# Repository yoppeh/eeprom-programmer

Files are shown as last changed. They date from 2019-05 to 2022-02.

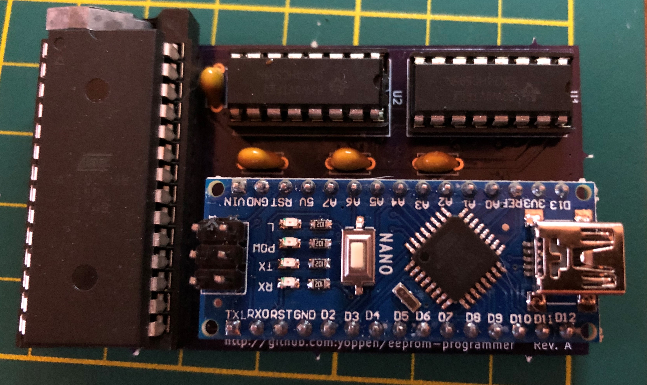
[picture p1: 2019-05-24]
populated-board.jpg

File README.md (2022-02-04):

# eeprom-programmer
An Arduino Nano sketch and schematic for an Atmel 28cx programmer. The schematic started out only targeting 8kx8 chips (rev. A) but has been updated to connect all address lines for the 28cx series (rev. B), so any of those eeproms should work up to the 32kx8 chips. The design is based on [this one](https://youtu.be/K88pgWhEb1M), from Ben Eater. 

The Arduino Nano sketch implements a serial interface to the programmer. It accepts one-letter commands:
- e - erase the eeprom
- f - fill eeprom with incrementing bytes
- h - help (this) text
- l - lock the eeprom against writes
- r - read and dump eeprom contents
- s - set the size of the eeprom
- u - unlock eeprom writes
- v - software version info
- x - xmodem transfer binary file to eeprom

Any standard terminal program can be used to talk to the programmer. I use the following:
- [serial](http://www.decisivetactics.com/products/serial/) for the Mac
- [teraterm](https://ttssh2.osdn.jp/index.html.en) for Windows
- [minicom](https://linux.die.net/man/1/minicom) for Linux

Be sure to set the size of your target eeprom with the s command before doing anything. It doesn't affect the chip in any way, but tells the programmer what size your chip is for the erase, fill and read commands and error checking in the xmodem transfer.

The programmer uses standard x-modem, as provided by any respectable terminal program—and certainly all of the
above listed terminal programs—to put binary files onto the eeprom. No other software is required. The programmer
will verify every 64 bytes as they are written (the size of an internal eeprom page).

Although the eeprom chips are supposed to come from the factory unlocked, I've heard stories of some chips being
purchased off ebay that arrive locked. Try doing an unlock on a chip if you have problems writing to it.

When doing an xmodem transfer to the chip, the program will wait indefinitely for you to start the xmodem transfer from your terminal software. You can abort the transfer at this point by pressing the ESC key. Otherwise, once you have started the transfer, it will continue until the process completes or an error is detected.

If you want to fill the eeprom with a specific byte, say the 6502 nop 0xea, just change

    fill[j] = i + j; 
on line 490 to

    fill[j] = 0xea;

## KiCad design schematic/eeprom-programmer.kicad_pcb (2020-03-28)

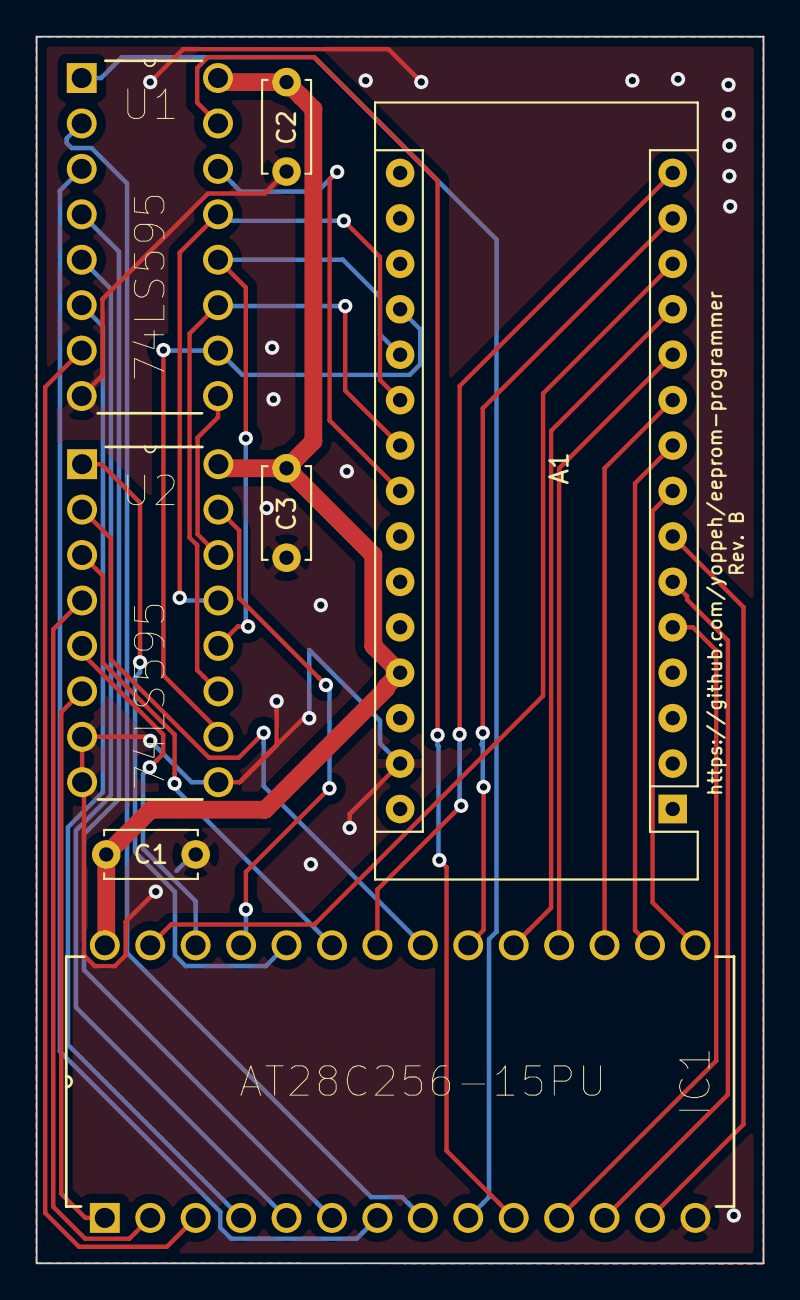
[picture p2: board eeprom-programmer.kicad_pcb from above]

Board: 2 copper layers, 40.6 x 68.6 mm, 7 parts (0 on the bottom side), 34 nets.

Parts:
A1: Arduino_Nano_v3.x; Arduino_Nano
C1, C2, C3: .1uf; C_Disc_D5.0mm_W2.5mm_P5.00mm
IC1: AT28C256-15PU; DIP254P1524X482-28
U1, U2: 74LS595; DIP254P762X508-16

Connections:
/addr00: IC1.10, U1.15
/addr01: IC1.9, U1.1
/addr02: IC1.8, U1.2
/addr03: IC1.7, U1.3
/addr04: IC1.6, U1.4
/addr05: IC1.5, U1.5
/addr06: IC1.4, U1.6
/addr07: IC1.3, U1.7
/addr08: IC1.25, U2.15
/addr09: IC1.24, U2.1
/addr10: IC1.21, U2.2
/addr11: IC1.23, U2.3
/addr12: IC1.2, U2.4
/addr13: IC1.26, U2.5
/addr14: IC1.1, U2.6
/data0: A1.5, IC1.11
/data1: A1.6, IC1.12
/data2: A1.7, IC1.13
/data3: A1.8, IC1.15
/data4: A1.9, IC1.16
/data5: A1.10, IC1.17
/data6: A1.11, IC1.18
/data7: A1.12, IC1.19
Arduino5V: A1.27, C1.2, C2.2, C3.2, IC1.28, U1.16, U2.16
GND: A1.29, C1.1, C2.1, C3.1, IC1.14, U1.8, U2.7, U2.8, U2.9
unnamed: U1.9, U2.14
eeNotChipEnable: A1.14, IC1.20
eeNotOutputEnable: A1.15, IC1.22
eeNotWriteEnable: A1.13, IC1.27
srNotOutputEnable: A1.21, U1.13, U2.13
srNotResetAll: A1.19, U1.10, U2.10
srReadClock: A1.20, U1.12, U2.12
srSerialClock: A1.22, U1.11, U2.11
srSerialData: A1.23, U1.14

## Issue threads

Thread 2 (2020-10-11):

using assignment operator instead of equality

btb, 2020-10-11:
you can't ever change the chip size because this always sets it back to 32768.

https://github.com/yoppeh/eeprom-programmer/blob/cc0bb88c09d81108247c1df810ca0ff00aa799d6/eeprom-programmer.ino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

btb, 2020-10-11:
well, I guess you can actually change it to 8192, in which case this line won't get reached, but if one is to modify this code to add more sizes, this will get in the way.

yoppeh, 2020-10-11:
Good eye, thank you!

Closed 2020-10-11.

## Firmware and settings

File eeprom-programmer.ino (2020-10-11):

/*******************************************************************************
 * eeprom-programmer.ino
 * 
 * Arduino Nano code for the at28c64b-15pu programmer. Note that this code is 
 * specific to the Nano (really, the ATmega328P). If you use this on another 
 * device, either make sure the port mappings are the same or you will need to
 * rewrite most of the code to use the correct mappings.
 *
 * I haven't looked at other EEPROMs, so I don't know how easy/difficult it 
 * would be to adapt this code to one. I'm not even sure if the pinouts for the
 * address lines or page sizes for the block write operations are the same
 * for different sizes of this same chip.
 *
 * The clock speed of the Nano (16MHz) is also assumed for getting the number
 * of nops to use for delays: 1 nop = 1 clock cycle = 1 / speed in MHz. So,
 * in the case of the Nano, 1 nop = 1 / 16000000 = 62.5ns.
 * 
 * Serial port settings:
 *  57600, 8n1, no flow control
 *
 * If you want to use other than 57600, change the SERIAL_BAUD constant below.
 *  
 * Terminal settings:
 *  turn off local echo
 *  Newline receive: LF
 *  Newline transmit: LF
 */


/* These are used in the x-modem protocol */
#define CHAR_SOH                0x01
#define CHAR_EOT                0x04
#define CHAR_ACK                0x06
#define CHAR_NAK                0x15
#define CHAR_ETB                0x17
#define CHAR_CAN                0x18
#define CHAR_ESC                0x1b
#define CHAR_C                  0x43

#define XMODEM_RETRIES          10
#define XMODEM_DELAY            2000
#define XMODEM_PACKET_MAX       128

/* Serial commands accepted by the programmer */
#define CMD_ERASE               'e'
#define CMD_FILL                'f'
#define CMD_HELP                'h'
#define CMD_LOCK                'l'
#define CMD_READ                'r'
#define CMD_SIZE                's'
#define CMD_UNLOCK              'u'
#define CMD_VERSION             'v'
#define CMD_XMODEM              'x'

/* Software version
 */
#define VERSION_MAJ             1
#define VERSION_MIN             2
#define VERSION_BLD             0

/* Change this to match whatever baud rate you want to use for the serial 
 * connection. 
 */
#define SERIAL_BAUD             57600

/* Set this to the size, in bytes of the EEPROM. In the case of the at28c64b,
 * it's 8k. 
 */
#define DEFAULT_EEPROM_SIZE     32768
#define PAGE_SIZE               64

/* Milliseconds to wait for a write to complete. */
#define WRITE_DELAY             25


/* Pin assignments
 *
 * These pin assigments correspond to these port mappings on the Atmega328P
 * (and Atmega168):
 *
 * x4HC595 shift registers
 *     PORTC, bit 4 = serial data pin (SER)
 *     PORTC, bit 3 = serial clock pin (SRCLK)
 *     PORTC, bit 2 = serial output enable (/OE)
 *     PORTC, bit 1 = serial read clock (RCLK)
 *     PORTC, bit 0 = reset all (/SRCLR)
 *
 * at28c64b eeprom
 *     PORTB, bit 4 = eeprom output enable (/OE)
 *     PORTB, bit 3 = eeprom chip enable (/CE)
 *     PORTB, bit 2 = eeprom write enable (/WE)
 *     PORTB, bit 1 = I/O7
 *     PORTB, bit 0 = I/O6
 *     PORTD, bit 7 = I/O5
 *     PORTD, bit 6 = I/O4  
 *     PORTD, bit 5 = I/O3
 *     PORTD, bit 4 = I/O2
 *     PORTD, bit 3 = I/O1
 *     PORTD, bit 2 = I/O0
 */
const int srSerialData = A4;
const int srSerialClock = A3;
const int srNotOutputEnable = A2;
const int srReadClock = A1;
const int srNotResetAll = A0;
const int eeNotWriteEnable = 10;
const int eeNotChipEnable = 11;
const int eeNotOutputEnable = 12;
const int eeD0 = 2;
const int eeD1 = 3;
const int eeD2 = 4;
const int eeD3 = 5;
const int eeD4 = 6;
const int eeD5 = 7;
const int eeD6 = 8;
const int eeD7 = 9;

unsigned int eeprom_size = DEFAULT_EEPROM_SIZE;


/* Clear the outputs of all shift registers to 0 by toggling the /srclr line.
 * /SRCLR needs to be low for 120ns, worst case. That's 3 nops, counting a
 * nop as 60ns.
 */
void sr_clear(void)
{
    PORTC = B00000100;
    __asm__ __volatile__ ("nop\n\t");
    __asm__ __volatile__ ("nop\n\t");
    __asm__ __volatile__ ("nop\n\t");
    PORTC = B00000101;
}


/* Setup the shift registers and shift in an address bit. Assumes that the bit
 * in question has already been shifted into bit 4: so, in the same position as
 * the "1" here: 00010000.
 */
void __attribute__((always_inline)) sr_shift_bit(byte bit)
{
    bit &= B00010000;
    // clear clock and data lines
    PORTC = B00000101 | bit;
    __asm__ __volatile__ ("nop\n\t");
    PORTC = B00001101 | bit;
    __asm__ __volatile__ ("nop\n\t");
}


/* Shifts out a given address on the 74HC595s.
 *
 * This is all about speed: no loops, no digitalRead()/Write(), always inline.
 * It's expected that the proper directions for the PORT bits used here are
 * already setup properly. Namely, PORTC bits 3 and 4 should be setup for
 * output.
 *
 * The observant programmer may notice we shift 16 bits onto the address lines.
 * This isn't a problem, even though we only have 13 address lines (on the
 * targetted 8k x 8 chip, chips with more memory, of course, will have more
 * address lines). The upper three bits simply aren't connected to anything and
 * the order in which the bits go out the shift registers guarantees that the
 * lower bits are always in the right place, no matter how many bits are 
 * shifted out. If this ends up being used with a larger EEPROM, then this
 * function at least won't have to be modified.
 */
void __attribute__((always_inline)) sr_address(word address)
{ 
    // disable output
    PORTC |= B00000100;

    // shift the address into the shift registers
    sr_shift_bit(address >> 11);
    sr_shift_bit(address >> 10);
    sr_shift_bit(address >> 9);
    sr_shift_bit(address >> 8);
    sr_shift_bit(address >> 7);
    sr_shift_bit(address >> 6);
    sr_shift_bit(address >> 5);
    sr_shift_bit(address >> 4);
    sr_shift_bit(address >> 3);
    sr_shift_bit(address >> 2);
    sr_shift_bit(address >> 1);
    sr_shift_bit(address);
    sr_shift_bit(address << 1);
    sr_shift_bit(address << 2);
    sr_shift_bit(address << 3);
    sr_shift_bit(address << 4);

    // make sure the clock and data lines are clear
    PORTC = B00000101;
    
    // put the address on the output pins by setting output enable low
    // and setting the read clock high
    PORTC = B00000011;
}


/* Puts a data value onto the data bus. The lower six bits of the data bus go
 * to the upper 6 bits of PORTD. PORTB's lower two bits hold the the upper two
 * bits of data. Again, this is about speed: The function is inline and uses
 * direct PORT writes. It's expected that all data pins are setup as OUTPUT
 * prior to this function being invoked.
 */
void __attribute__((always_inline)) write_data(byte data)
{
    PORTD = ((PORTD & B00000011) | (data << 2));
    PORTB = ((PORTB & B11111100) | (data >> 6));
}


/* Reads the data value in the EEPROM at the address currently on the address
 * pins. Assumes that the I/O lines are already setup as INPUTs and that the
 * /OE line is set properly.
 */
byte __attribute__((always_inline)) read_data(void)
{
    return ((PIND >> 2) | (PINB << 6));
}


/* Set all I/O (data) pins to output 
 */
void io_set_output(void)
{
    // all data pins are outputs
    DDRD |= B11111100;
    DDRB |= B00000011;
}


/* Set all I/O (data) pins to input 
 */
void io_set_input(void)
{
    // all data pins are inputs
    DDRD &= B00000011;
    DDRB &= B11111100;
}


/* Executes the appropriate write sequence to enable the software locking
 * mechanism of the chip. After this function executes, the chip will not
 * recognize writes unless unlock_chip() is called.
 */
int lock_chip(void)
{
    // Setup a known state. Enable chip.
    digitalWrite(eeNotChipEnable, LOW);
    digitalWrite(eeNotOutputEnable, HIGH);
    digitalWrite(eeNotWriteEnable, HIGH);

    // Set data lines to outputs
    io_set_output();

    // aah to address 1555h
    sr_address(0x1555);
    write_data(0xaa);
    digitalWrite(eeNotWriteEnable, LOW);
    digitalWrite(eeNotWriteEnable, HIGH);

    // 55h to address 0aaah
    sr_address(0x0aaa);
    write_data(0x55);
    digitalWrite(eeNotWriteEnable, LOW);
    digitalWrite(eeNotWriteEnable, HIGH);

    // a0h to address 1555h
    sr_address(0x1555);
    write_data(0xa0);
    digitalWrite(eeNotWriteEnable, LOW);
    digitalWrite(eeNotWriteEnable, HIGH);

    delay(WRITE_DELAY);

    return 1;
}


/* Disables the software write protect mechanism.
 */
int unlock_chip(void)
{
    // Setup a known state. Enable chip.
    digitalWrite(eeNotChipEnable, LOW);
    digitalWrite(eeNotOutputEnable, HIGH);
    digitalWrite(eeNotWriteEnable, HIGH);

    // Set data lines to outputs
    io_set_output();

    // aah to address 1555h
    sr_address(0x1555);
    write_data(0xaa);
    digitalWrite(eeNotWriteEnable, LOW);
    digitalWrite(eeNotWriteEnable, HIGH);

    // 55h to address 0aaah
    sr_address(0x0aaa);
    write_data(0x55);
    digitalWrite(eeNotWriteEnable, LOW);
    digitalWrite(eeNotWriteEnable, HIGH);

    // 80h to address 1555h
    sr_address(0x1555);
    write_data(0x80);
    digitalWrite(eeNotWriteEnable, LOW);
    digitalWrite(eeNotWriteEnable, HIGH);

    // aah to address 1555h
    sr_address(0x1555);
    write_data(0xaa);
    digitalWrite(eeNotWriteEnable, LOW);
    digitalWrite(eeNotWriteEnable, HIGH);

    // 55h to address 0aaah
    sr_address(0x0aaa);
    write_data(0x55);
    digitalWrite(eeNotWriteEnable, LOW);
    digitalWrite(eeNotWriteEnable, HIGH);

    // 20h to address 1555h
    sr_address(0x1555);
    write_data(0x20);
    digitalWrite(eeNotWriteEnable, LOW);
    digitalWrite(eeNotWriteEnable, HIGH);

    delay(WRITE_DELAY);

    return 1;
}


/* Writes a single input byte at a specified address.
 */
int write_byte(word address, byte data) 
{
    // set data lines as outputs
    io_set_output();

    // setup initial chip state
    digitalWrite(eeNotChipEnable, LOW);
    digitalWrite(eeNotOutputEnable, HIGH);
    digitalWrite(eeNotWriteEnable, HIGH);
    
    // set the address pins from the shift registers
    sr_address(address);

    // put the data on the EEPROM's i/o pins
    write_data(data);
    
    // setup the we-controlled write state
    digitalWrite(eeNotWriteEnable, LOW);
    
    // end the write state
    digitalWrite(eeNotWriteEnable, HIGH);

    delay(WRITE_DELAY);
    
    // byte was successfully written
    return 1;
}


/* Write a page of a given length (64 bytes max) at a given address.
 */
int write_page(word address, byte *data, byte len)
{
    // all data pins are outputs
    io_set_output();

    // setup initial state for control lines
    digitalWrite(eeNotChipEnable, LOW);
    digitalWrite(eeNotOutputEnable, HIGH);
    digitalWrite(eeNotWriteEnable, HIGH);

    while (len--) {
        // put address into shift registers
        sr_address(address++);
        // put data byte on EEPROM pins
        write_data(*data++);
        // bring write enable low
        digitalWrite(eeNotWriteEnable, LOW);
        // bring write enable high
        digitalWrite(eeNotWriteEnable, HIGH);
    }

    // turn off write state
    digitalWrite(eeNotWriteEnable, HIGH);
    digitalWrite(eeNotOutputEnable, LOW);

    // wait for updates to be committed to chip
    delay(WRITE_DELAY);
    
    return 1;
}


/* Write an xmodem packet 1 EEPROM page at a time. 
 */
void write_packet(word address, byte *data, word len)
{
    word i;
    
    for (i = 0; i < len; i += PAGE_SIZE, data += PAGE_SIZE) {
        write_page(address + i, data, PAGE_SIZE);
    }
}


/* Very that the received xmodem packet matches what was
 * written to the EEPROM.
 */
int verify_packet(word address, byte *data, word len)
{
    word i;

    for (i = 0; i < len; i++, address++, data++) {
        if (read_byte(address) != *data) {
            return 0;
        }
    }
    return 1;
}


/* Erase the EEPROM by writing all 1s to it. We do it this way, since the
 * hardware isn't there to do a hardware erase. That would require putting
 * a 12 volt line in the circuit, and... why bother...
 */
int erase_eeprom(void)
{
    byte fill[] = {
        0xff, 0xff, 0xff, 0xff, 0xff, 0xff, 0xff, 0xff, 
        0xff, 0xff, 0xff, 0xff, 0xff, 0xff, 0xff, 0xff,
        0xff, 0xff, 0xff, 0xff, 0xff, 0xff, 0xff, 0xff,
        0xff, 0xff, 0xff, 0xff, 0xff, 0xff, 0xff, 0xff,
        0xff, 0xff, 0xff, 0xff, 0xff, 0xff, 0xff, 0xff, 
        0xff, 0xff, 0xff, 0xff, 0xff, 0xff, 0xff, 0xff,
        0xff, 0xff, 0xff, 0xff, 0xff, 0xff, 0xff, 0xff, 
        0xff, 0xff, 0xff, 0xff, 0xff, 0xff, 0xff, 0xff
    };
    word i;
    for (i = 0; i < eeprom_size; i += PAGE_SIZE) {
        if (i % 1024 == 0) {
            Serial.print(".");
        }
        if (!write_page(i, fill, PAGE_SIZE)) {
            return 0;
        }
    }
    return 1;
}


/* Returns the byte at the given address in the EEPROM.
 */
byte read_byte(word address)
{
    byte data;
    
    digitalWrite(eeNotOutputEnable, HIGH);
    digitalWrite(eeNotWriteEnable, HIGH);
    digitalWrite(eeNotChipEnable, LOW);
    
    // all data pins are inputs
    io_set_input();
   
    sr_address(address);
    
    digitalWrite(eeNotOutputEnable, LOW);
    
    data = read_data();

    digitalWrite(eeNotOutputEnable, HIGH);

    return data;
}


/* Writes a pattern to the EEPROM. The pattern is address = address & 0xff. So,
 * essentially, every address is set to the value of its lower 8 bits. I guess
 * that's the long way to say, it repeats from 0 to 255 until the end of memory.
 */
int write_pattern(void)
{
    byte fill[PAGE_SIZE];
    word i, j;
    for (i = 0; i < eeprom_size; i += PAGE_SIZE) {
        for (j = 0; j < PAGE_SIZE; j++) {
            fill[j] = i + j;
        }
        if (i % 1024 == 0) {
            Serial.print(".");
        }
        if (!write_page(i, fill, PAGE_SIZE)) {
            return 0;
        }
    }
    return 1;
}


/* Reads the entire EEPROM. Prints the data out in the format: 
 * aaaa  xx xx xx xx xx xx xx xx xx xx xx xx xx xx xx xx   ................
 * Where aaaa is the address in hex, xx is 16 bytes of data in hex and 
 * ............... is the ascii representation for each data byte, if it is 
 * printable.
 */
void read_eeprom(void)
{
    char s[6];
    word i, j;
    byte d;
    for (i = 0; i < eeprom_size; i += 16) {
        sprintf(s, "%04x ", i);
        Serial.print(s);
        for (j = 0; j < 16; j++) {
            sprintf(s, " %02x", read_byte(i + j));
            Serial.print(s);
        }
        Serial.print("  ");
        for (j = 0; j < 16; j++) {
            d = read_byte(i + j);
            sprintf(s, "%c", isprint(d) ? d : '.');
            Serial.print(s);
        }
        Serial.println("");
    }
}


/* Display terminal prompt
 */
void show_prompt(void)
{
    Serial.print("> ");
}


/* Display serial command help.
 */
void cmd_help(void)
{
    Serial.println("commands:");
    Serial.print(CMD_ERASE); Serial.println(" - erase the eeprom");
    Serial.print(CMD_FILL); Serial.println(" - fill eeprom with incrementing bytes");
    Serial.print(CMD_HELP); Serial.println(" - help (this) text");
    Serial.print(CMD_LOCK); Serial.println(" - lock the eeprom against writes");
    Serial.print(CMD_READ); Serial.println(" - read and dump eeprom contents");
    Serial.print(CMD_SIZE); Serial.print(" - set the size of the eeprom (currently "); Serial.print(eeprom_size / 1024); Serial.print("k x 8, ");
    if (eeprom_size == 8192) {
        Serial.print("AT28C64");
    } else if (eeprom_size == 32768) {
        Serial.print("AT28C256");
    } else {
        Serial.print("Unknown chip");
    }
    Serial.println(")");
    Serial.print(CMD_VERSION); Serial.println(" - print software version info");
    Serial.print(CMD_UNLOCK); Serial.println(" - unlock eeprom writes");
    Serial.print(CMD_XMODEM); Serial.println(" - xmodem transfer binary file to eeprom");
}

 
/* Initial board setup.
 */
void setup() 
{
    pinMode(srSerialData, OUTPUT);
    pinMode(srSerialClock, OUTPUT);
    pinMode(srNotOutputEnable, OUTPUT);
    pinMode(srReadClock, OUTPUT);
    pinMode(srNotResetAll, OUTPUT);
    pinMode(eeNotWriteEnable, OUTPUT);
    pinMode(eeNotChipEnable, OUTPUT);
    pinMode(eeNotOutputEnable, OUTPUT);
  
    pinMode(LED_BUILTIN, OUTPUT);
    
    pinMode(eeD0, OUTPUT);
    pinMode(eeD1, OUTPUT);
    pinMode(eeD2, OUTPUT);
    pinMode(eeD3, OUTPUT);
    pinMode(eeD4, OUTPUT);
    pinMode(eeD5, OUTPUT);
    pinMode(eeD6, OUTPUT);
    pinMode(eeD7, OUTPUT);
  
    sr_clear();

    digitalWrite(srSerialData, LOW);
    digitalWrite(srSerialClock, LOW);
    digitalWrite(srNotOutputEnable, HIGH);
    digitalWrite(srReadClock, LOW);
    
    digitalWrite(eeNotWriteEnable, HIGH);
    digitalWrite(eeNotChipEnable, LOW);
    digitalWrite(eeNotOutputEnable, HIGH);
    
    Serial.begin(SERIAL_BAUD);
    cmd_help();
    show_prompt();
}


/* Flush the serial input buffer
 */
void flush_serial_input(void)
{
    while (Serial.available()) {
        Serial.read();
    }
}


/* Sends the xmodem abort sequence out the serial port.
 */
void abort_xmodem(char *s)
{
    int i;

    for (i = 0; i < 8; i++) {
        Serial.write(CHAR_CAN);
        Serial.flush();
        delay(1000);
    }
    Serial.print("transfer aborted: ");
    Serial.println(s);
    flush_serial_input();
}


/* Read the next available byte from the serial port.
 */
int read_serial(void)
{
    while (!Serial.available());
    return Serial.read();
}


/* Erase the EEPROM.
 */
void cmd_erase(void)
{
    Serial.print("erasing eeprom ");
    if (!erase_eeprom()) {
        Serial.println(" error");
        return;
    } else {
        Serial.println(" ok");
    }
}


/* Fill the EEPROM with a sequence.
 */
void cmd_fill(void)
{    
    Serial.print("filling eeprom ");
    if (!write_pattern()) {
        Serial.println(" error");
        return;
    } else {
        Serial.println(" ok");
    }
}


/* Lock the chip against writes.
 */
void cmd_lock(void)
{
    Serial.print("locking chip ... ");
    if (lock_chip()) {
        Serial.println("ok");
    } else {
        Serial.println("error");
    }
}


/* Read the entire EEPROM.
 */
void cmd_read(void)
{
    Serial.println("reading eeprom:");
    read_eeprom();
    Serial.println("all addresses read");
}


/* Display size command help 
*/
void cmd_size_help(void)
{
    Serial.println("select new eeprom size:");
    Serial.println("1 - 8k x 8 (AT28C64)");
    Serial.println("2 - 32k x 8 (AT28C256)");
    Serial.println("any other key to cancel");
}


/* Set the EEPROM size.
 */
 void cmd_size(void)
 {
    int ch;
    cmd_size_help();
    show_prompt();
    ch = read_serial();
    if (ch == '1') {
        eeprom_size = 8192;
    } else if (ch == '2') {
        eeprom_size = 32768;
    } else {
        Serial.println("");
        return;
    }
    Serial.print("eeprom size set to "); Serial.print(eeprom_size / 1024); Serial.print("k x 8 (");
    if (eeprom_size == 8192) {
        Serial.print("AT28C64");
    } else if (eeprom_size == 32768) {
        Serial.print("AT28C256");
    }
    Serial.println(")");
    Serial.println("");
    cmd_help();
 }

 
/* Print software info.
 */
void cmd_version(void)
{
    char version[12];
    Serial.println("software version info:");
    sprintf(version, "%02i\.%02i.%02i", VERSION_MAJ, VERSION_MIN, VERSION_BLD);
    Serial.print("version: ");
    Serial.println(version);
}


/* Disable software write protection.
 */
void cmd_unlock(void)
{
    Serial.print("unlocking chip ... ");
    if (unlock_chip()) {
        Serial.println("ok");
    } else {
        Serial.println("error");
    }
}


/* Read the next available byte from the serial port.
 */
int xmodem_read_serial(void)
{
    unsigned long start = millis();
    while (!Serial.available()) {
        if (millis() - start >= XMODEM_DELAY) {
            return -1;
        }
    }
    return Serial.read();
}


/* Print packet data
 */
 void print_packet_data(byte *packet) {
    char s[3];
    for (int i = 1; i <= XMODEM_PACKET_MAX; i++) {
        sprintf(s, "%02x ", packet[i - 1]);
        Serial.print(s);
        if (i % 16 == 0) {
            Serial.println("");
        }
    }
 }
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
void loop() 
{
    process_cmd(read_serial());
    show_prompt();            
}

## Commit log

2019-04-11 Tidy up the schematic a bit
    [at28c64b-15pu-programmer.sch]
2019-04-17 Rearrange the repo
    [at28c-programmer-backup.kicad_pcb, at28c-programmer-backup.sch, at28c64b-15pu-programmer.kicad_pcb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]
2019-04-17 Add local library
    [at28c-programmer-backup.kicad_pcb, at28c-programmer-backup.sch, at28c64b-15pu-programmer.kicad_pcb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]
2019-04-17 Rename files
    [eeprom-programmer.sch]
2019-04-17 Readd Arduino and EEPROM symbols
    [eeprom-programmer.sch]
2019-04-17 Remove excess wires
    [eeprom-programmer.sch]
2019-04-17 Add busses
    [eeprom-programmer.sch]
2019-04-17 Tighten up schematic
    [eeprom-programmer.sch]
2019-04-18 Add PCB
    [at28c64b-15pu-programmer.kicad_pcb, at28c64b-15pu-programmer.sch, eeprom-programmer.kicad_pcb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]
2019-04-19 Initial PCB routing
    [eeprom-programmer.kicad_pcb]
2019-04-19 Fix issues for OSHPARK submission
    [eeprom-programmer.kicad_pcb]
2019-04-20 First prototype board
    [eeprom-programmer.sch]
2019-05-04 Port mappings changed for PCB
2019-05-04 Change revision to 'a'
    [eeprom-programmer.sch]
2019-05-06 Update for schematic changes
2019-05-07 Begin new layout using better design limits
    [eeprom-programmer.kicad_pcb]
2019-05-07 Rearrange parts
    [eeprom-programmer.kicad_pcb]
2019-05-07 Add routing
    [eeprom-programmer.kicad_pcb]
2019-05-08 Add edge cuts
    [eeprom-programmer.kicad_pcb]
2019-05-08 Add ground fills and silkscreen
    [eeprom-programmer.kicad_pcb]
2019-05-08 Update solder mask clearance for Osh Park specs
    [eeprom-programmer.kicad_pcb]
2019-05-08 Right justify silkscreen ID text
    [eeprom-programmer.kicad_pcb]
2019-05-09 Fix permissions
    [eeprom-programmer.kicad_pcb]
2019-05-24 Add image of populated board
2019-12-06 Updated schematic to handle up to 32Kx8 eeproms with no rewiring
    [eeprom-programmer.sch]
2019-12-07 Fixed timeout too fast waiting for user to start xmodem transfer
    [eeprom-programmer.ino]
2019-12-07 Update README to warn current PCB layout only supports 8kx8 roms
2020-01-04 Update PCB layout to handle up to 64kx8 eeproms
    [eeprom-programmer.kicad_pcb, eeprom-programmer.sch]
2020-03-28 Update PCB layout to handle up to 32kx8 eeproms
    [eeprom-programmer.kicad_pcb, eeprom-programmer.sch]
2020-10-11 Fix assigment instead of comparison
    [eeprom-programmer.ino]
